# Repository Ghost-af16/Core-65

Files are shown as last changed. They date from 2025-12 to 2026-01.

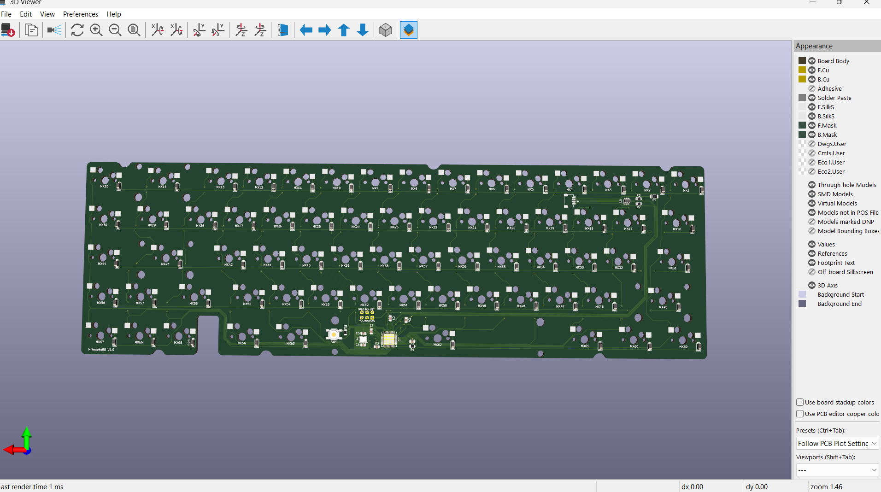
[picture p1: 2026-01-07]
Cart screenshot/Screenshot 2025-12-18 214639.png

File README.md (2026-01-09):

# Core-65
guyss, its a simple 65% layout keyboard with 65 mechanical keys

# FEATURES 
1->> Full Of Functionable Keys 65 </n>

2->> Fully Customizable { Modify The Code For Ur Own Functioning }</n>

# IMAGESSS

















Bill of Materials (BOM)

| Component | Quantity | Specification | Unit Price | Total Price |
|---|---|---|---|---|
| PCB | 5 | Custom PCB | $20 with shipping | $20 with shipping |
| ATMEGA32U4-MU | 1 | Microchip MCU | $6 with shipping | $6 with shipping |
| Crystal | 1 | 16 MHz | $1 with shipping | $1 with shipping |
| Capacitor | 2 | 22 pF | $1 with shipping | $1 with shipping |
| USB-C Receptacle | 1 | USB Type-C | $5 with shipping | $6 with shipping |
| Resistor | 1 | 5.1 kΩ | $0.50 with shipping | $1 with shipping |
| Resistor | 1 | 22 kΩ | $2 with shipping | $2 with shipping |
| Capacitor | 1 | 10 µF | $0.50 with shipping | $1 with shipping |
| Capacitor | 1 | 1 µF | $0.25 with shipping | $1 with shipping |
| Capacitor | 6 | 0.1 µF (100 nF) | $1 with shipping | $2 with shipping |
| Ferrite Bead | 1 | 600 Ω @ 100 MHz | $0.01 with shipping | $0.50 with shipping |
| Key Switch | 68 | Crystal Pro Switch | $33 with shipping | $33 with shipping |
| Key caps | 68 | Blank white cherry | $13 with shipping | $13 with shipping |
| Type c cable | 1 | Type c cable | $7 with shipping | $7 with shipping |
| 3D Printed Case | 1 | Custom 3D Printed Case | Printing Legion | Printing Legion |

## JLCPCB


**INDIA IS GODDAMMED EXPENSIVE MAN**

**Total Estimated Cost**: `$95 WITH SHIPPING CHARGES INCLUDED`

I'm some of the components thats why i'm only asking for the components i dont have

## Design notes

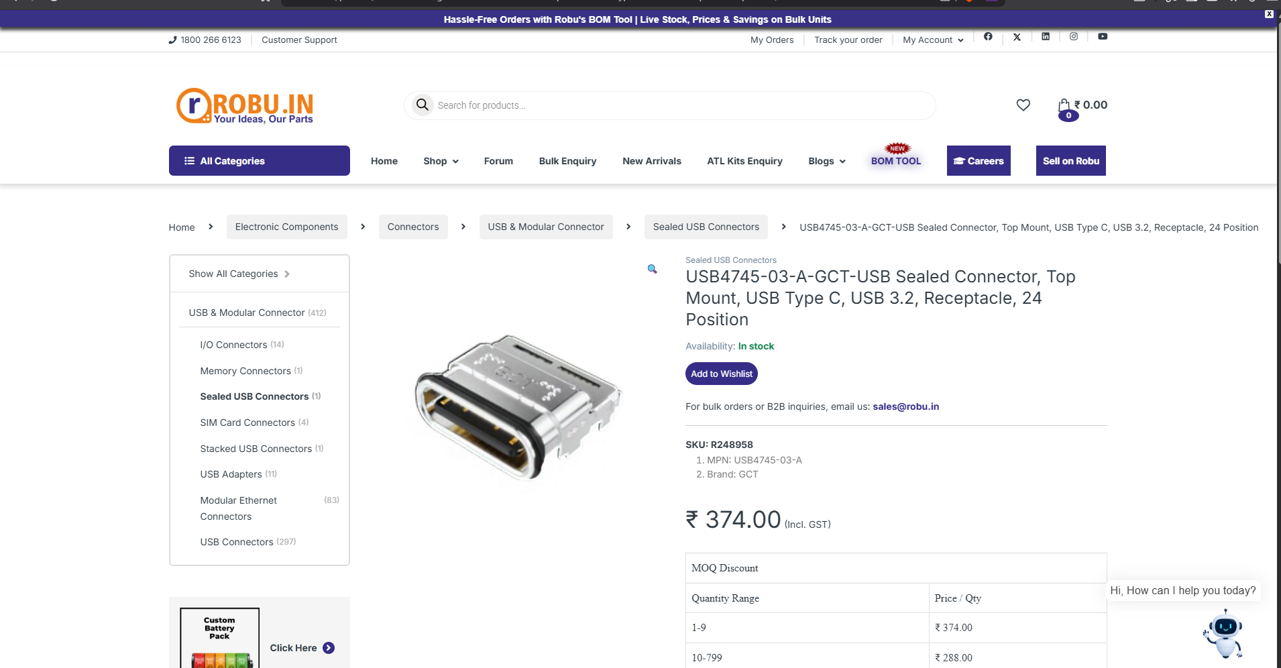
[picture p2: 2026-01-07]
Cart screenshot/Screenshot 2025-12-19 234429.png

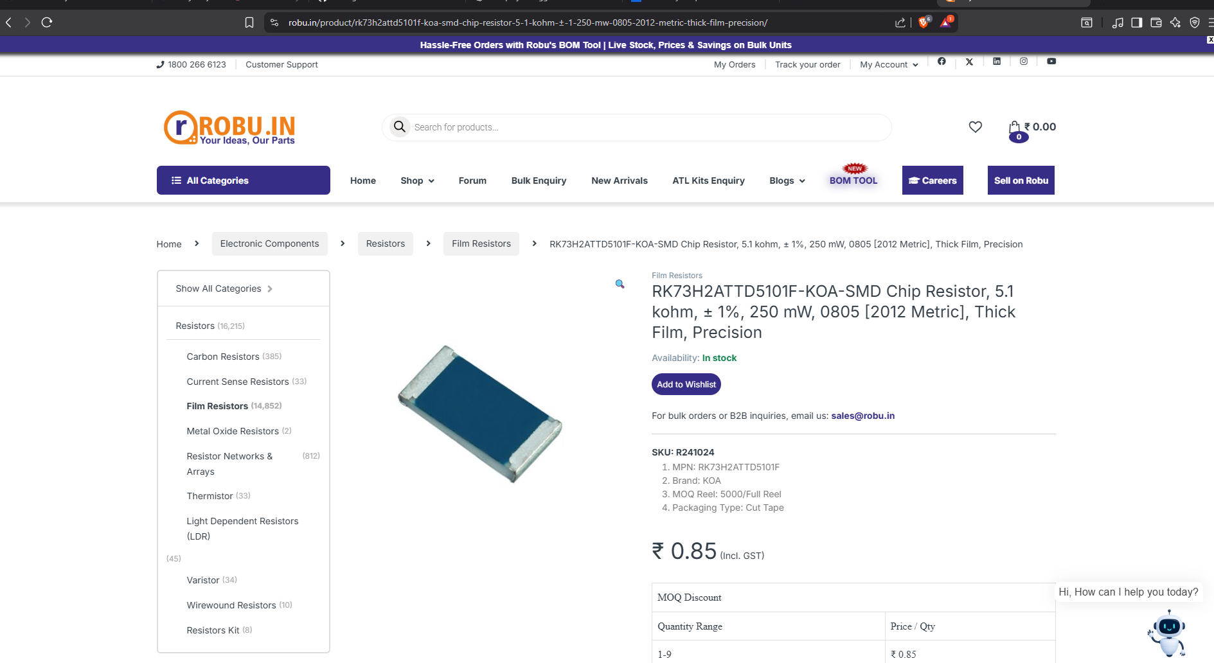
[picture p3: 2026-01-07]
Cart screenshot/Screenshot 2025-12-19 234724.png

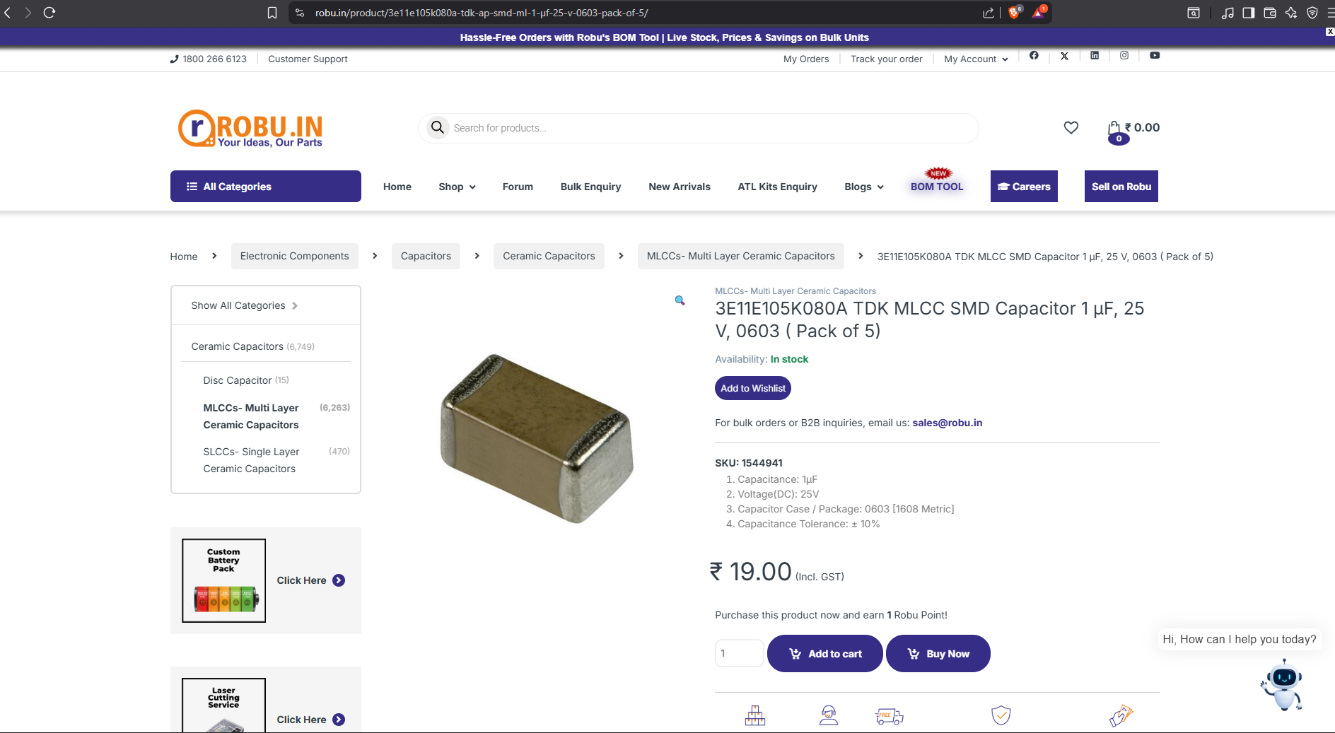
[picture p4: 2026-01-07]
Cart screenshot/Screenshot 2025-12-19 235857.png

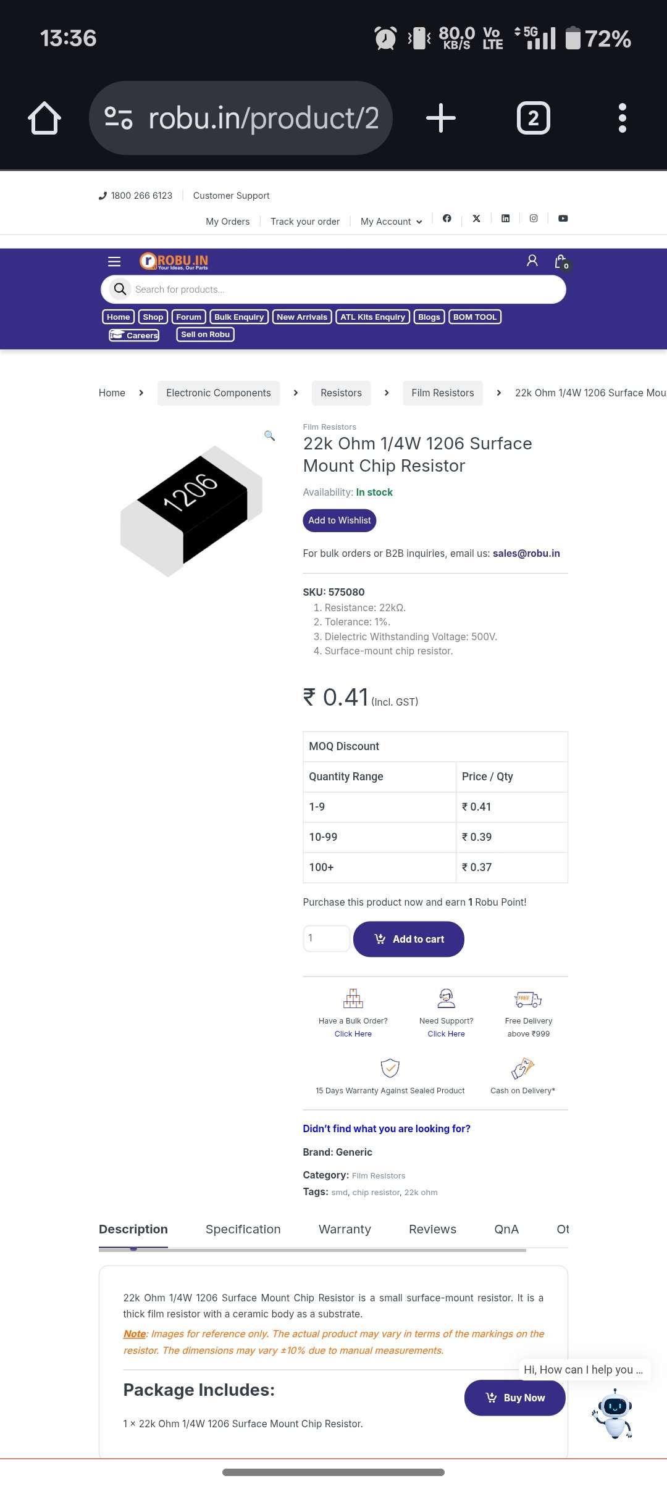
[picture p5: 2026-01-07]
Cart screenshot/Screenshot_2026-01-07-13-36-53-74_40deb401b9ffe8e1df2f1cc5ba480b12.jpg

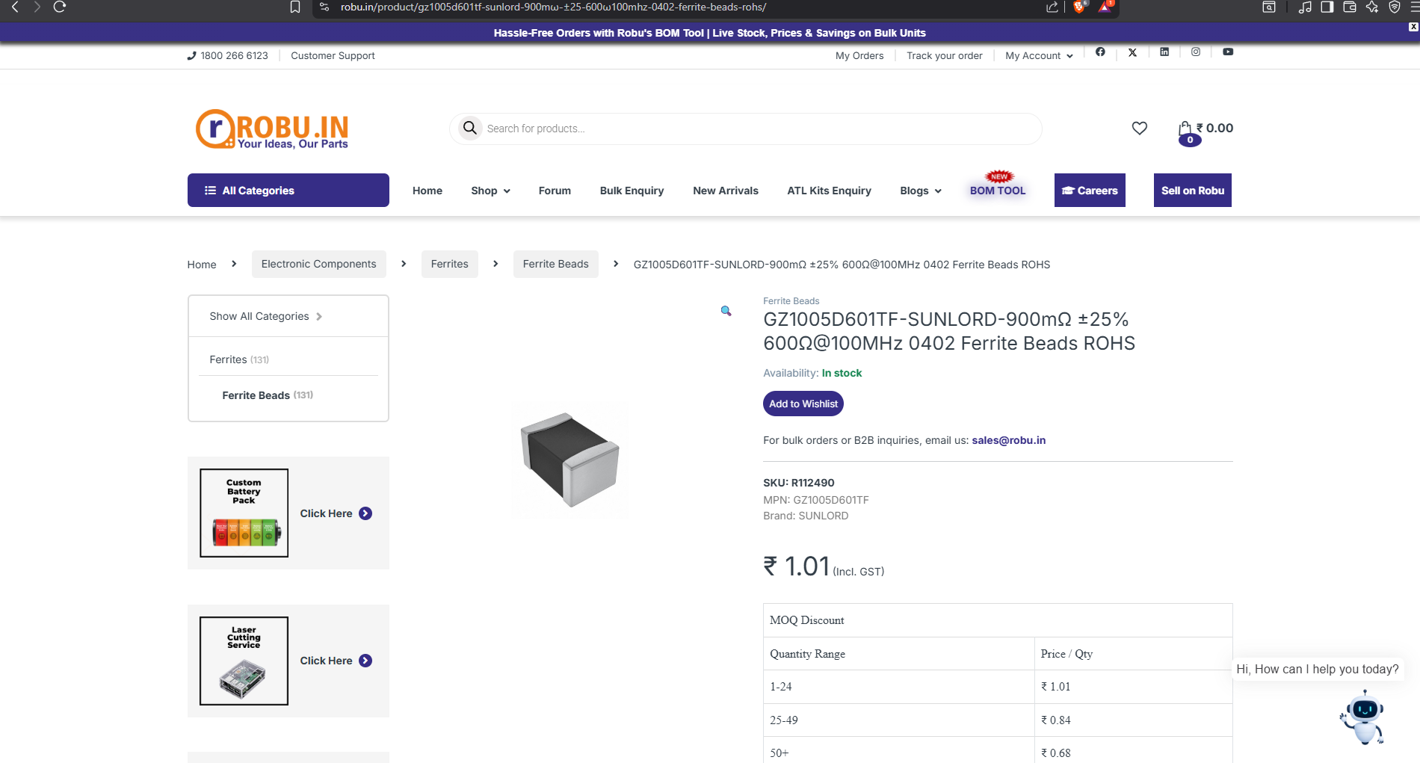
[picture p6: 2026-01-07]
Cart screenshot/Screenshot 2025-12-20 000124.png

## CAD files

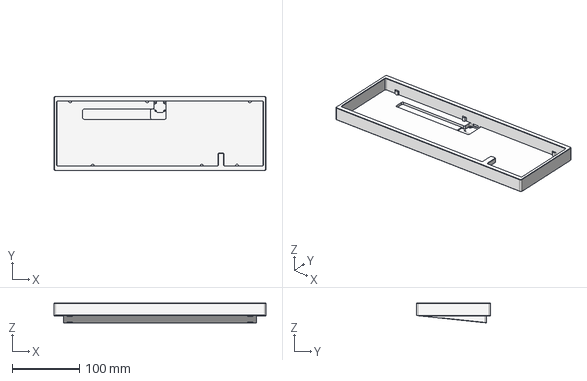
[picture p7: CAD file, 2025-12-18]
CAD/Core-65-bottom case.step
314.8 x 110.2 x 29.4 mm

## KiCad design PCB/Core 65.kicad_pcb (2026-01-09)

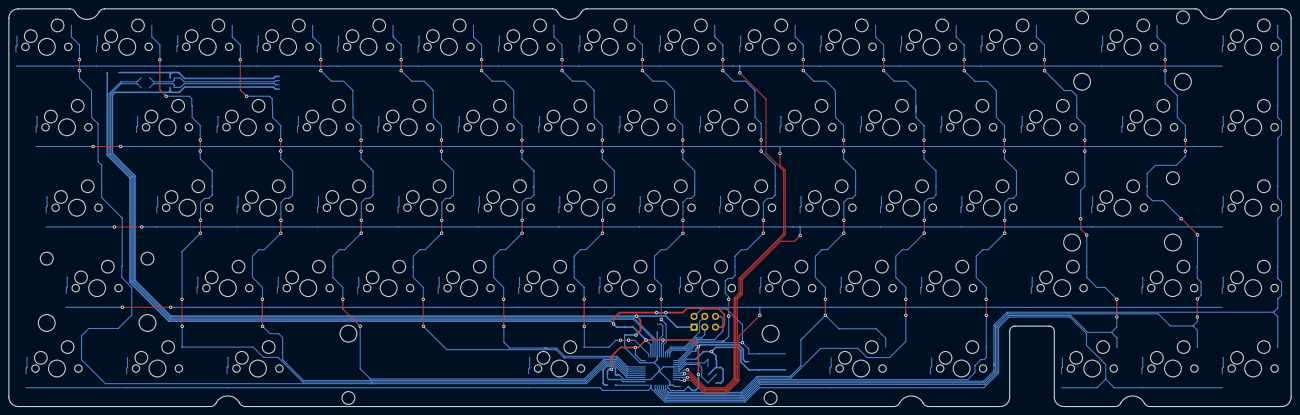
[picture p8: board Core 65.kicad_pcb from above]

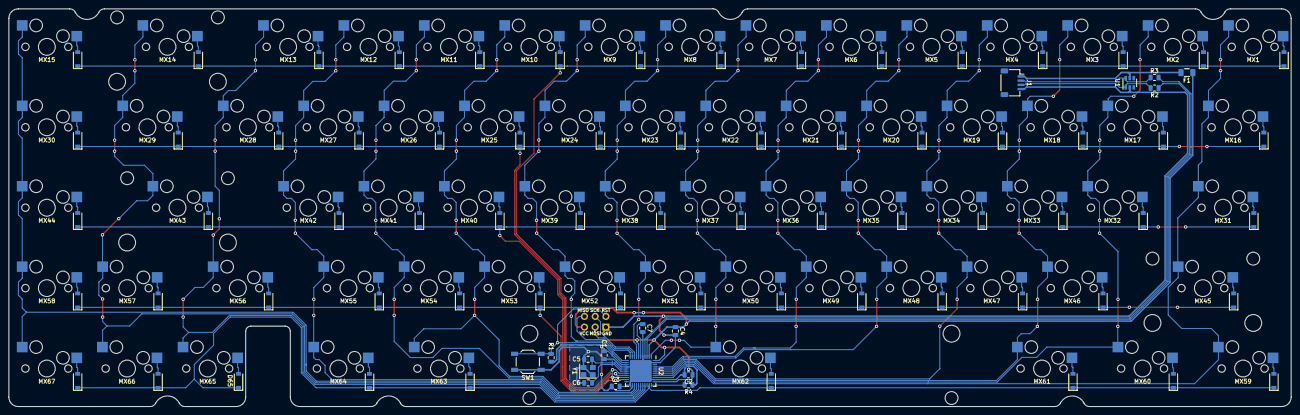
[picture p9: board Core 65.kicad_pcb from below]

Board: 2 copper layers, 303.8 x 94.2 mm, 152 parts (84 on the bottom side), 102 nets.

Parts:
C1, C2, C3: 0.1u; C_0805_2012Metric
C4: 10u; C_0805_2012Metric
C5, C6: 22p; C_0805_2012Metric
C7: 1u; C_0805_2012Metric
D1, D2, D3, D4, D5, D6, D7, D8, D9, D10, D11, D12, D13, D14, D15, D16, D17, D18, D19, D20, D21, D22, D23, D24, D25, D26, D27, D28, D29, D30, D31, D32, D33, D34, D35, D36, D37, D38, D39, D40, D41, D42, D43, D44, D45, D46, D47, D48, D49, D50, D51, D52, D53, D54, D55, D56, D57, D58, D59, D60, D61, D62, D63, D64, D65, D66, D67: 1N4148; D_SOD-123
F1: 500mA; Fuse_1206_3216Metric
J1: JST SH 4-pin; JST_SH_SM04B-SRSS-TB_1x04-1MP_P1.00mm_Horizontal
J2: AVR-ISP-6; ISP
MX1, MX2, MX3, MX4, MX5, MX6, MX7, MX8, MX9, MX10, MX11, MX12, MX13, MX15, MX17, MX18, MX19, MX20, MX21, MX22, MX23, MX24, MX25, MX26, MX27, MX28, MX30, MX32, MX33, MX34, MX35, MX36, MX37, MX38, MX39, MX40, MX41, MX42, MX44, MX46, MX47, MX48, MX49, MX50, MX51, MX52, MX53, MX54, MX55, MX57, MX58, MX65, MX66, MX67: 1u; MXOnly-1U-Hotswap
MX14: 2u; MXOnly-2U-Hotswap
MX16, MX29: 1.5u; MXOnly-1.5U-Hotswap
MX31, MX56: 1.75u; MXOnly-1.75U-Hotswap
MX43, MX45: 2.25u; MXOnly-2.25U-Hotswap
MX59, MX60, MX61, MX63, MX64: 1.25u; MXOnly-1.25U-Hotswap
MX62: 6.25u; MXOnly-6.25U-Hotswap-ReversedStabilizers
R1, R4: 10k; R_0805_2012Metric
R2, R3: 22; R_0805_2012Metric
SW1: Reset; SW_SPST_TL3342
U1: SRV05-4; SOT-23-6
U2: ATmega32U4-MUR; QFN-44-1EP_7x7mm_P0.5mm_EP5.2x5.2mm
Y1: 16MHz; Crystal_SMD_3225-4Pin_3.2x2.5mm

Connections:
+5V: C1.1, C2.1, C3.1, C4.1, F1.1, J2.2, R1.2, U2.2, U2.7, U2.14, U2.24, U2.34, U2.44
/MCU_D+: R2.1, U2.4
/MCU_D-: R3.1, U2.3
COL0: MX1.2, MX16.2, MX31.2, MX45.2, MX59.2, U2.36
COL1: MX2.2, MX17.2, MX32.2, MX60.2, U2.37
COL2: MX3.2, MX18.2, MX33.2, MX46.2, MX61.2, U2.38
COL3: MX4.2, MX19.2, MX34.2, MX47.2, U2.39
COL4: MX5.2, MX20.2, MX35.2, MX48.2, U2.40
COL5: MX6.2, MX21.2, MX36.2, MX49.2, U2.41
COL6: MX7.2, MX22.2, MX37.2, MX50.2, MX62.2, U2.1
COL7: MX8.2, MX23.2, MX38.2, MX51.2, U2.8
COL8: MX9.2, MX24.2, MX39.2, MX52.2, U2.12
COL9: MX10.2, MX25.2, MX40.2, MX53.2, MX63.2, U2.25
COL10: MX11.2, MX26.2, MX41.2, MX54.2, U2.26
COL11: MX12.2, MX27.2, MX42.2, MX55.2, MX64.2, U2.27
COL12: MX13.2, MX28.2, MX56.2, MX65.2, U2.30
COL13: MX14.2, MX29.2, MX43.2, MX57.2, MX66.2, U2.29
COL14: MX15.2, MX30.2, MX44.2, MX58.2, MX67.2, U2.28
D+: J1.3, R2.2, U1.1
D-: J1.2, R3.2, U1.6
GND: C1.2, C2.2, C3.2, C4.2, C5.1, C6.1, C7.2, J1.4, J2.6, R4.1, SW1.1, U1.2, U2.5, U2.15, U2.23, U2.35, U2.43, U2.45, Y1.2, Y1.4
MISO: J2.1, U2.11
MOSI: J2.4, U2.10
unnamed: C7.1, U2.6
unnamed: D1.2, MX1.1
unnamed: D2.2, MX2.1
unnamed: D3.2, MX3.1
unnamed: D4.2, MX4.1
unnamed: D5.2, MX5.1
unnamed: D6.2, MX6.1
unnamed: D7.2, MX7.1
unnamed: D8.2, MX8.1
unnamed: D9.2, MX9.1
unnamed: D10.2, MX10.1
unnamed: D11.2, MX11.1
unnamed: D12.2, MX12.1
unnamed: D13.2, MX13.1
unnamed: D14.2, MX14.1
unnamed: D15.2, MX15.1
unnamed: D16.2, MX16.1
unnamed: D17.2, MX17.1
unnamed: D18.2, MX18.1
unnamed: D19.2, MX19.1
unnamed: D20.2, MX20.1
unnamed: D21.2, MX21.1
unnamed: D22.2, MX22.1
unnamed: D23.2, MX23.1
unnamed: D24.2, MX24.1
unnamed: D25.2, MX25.1
unnamed: D26.2, MX26.1
unnamed: D27.2, MX27.1
unnamed: D28.2, MX28.1
unnamed: D29.2, MX29.1
unnamed: D30.2, MX30.1
unnamed: D31.2, MX31.1
unnamed: D32.2, MX32.1
unnamed: D33.2, MX33.1
unnamed: D34.2, MX34.1
unnamed: D35.2, MX35.1
unnamed: D36.2, MX36.1
unnamed: D37.2, MX37.1
unnamed: D38.2, MX38.1
unnamed: D39.2, MX39.1
unnamed: D40.2, MX40.1
unnamed: D41.2, MX41.1
unnamed: D42.2, MX42.1
unnamed: D43.2, MX43.1
unnamed: D44.2, MX44.1
unnamed: D45.2, MX45.1
unnamed: D46.2, MX46.1
unnamed: D47.2, MX47.1
unnamed: D48.2, MX48.1
unnamed: D49.2, MX49.1
unnamed: D50.2, MX50.1
unnamed: D51.2, MX51.1
unnamed: D52.2, MX52.1
unnamed: D53.2, MX53.1
unnamed: D54.2, MX54.1
unnamed: D55.2, MX55.1
unnamed: D56.2, MX56.1
unnamed: D57.2, MX57.1
unnamed: D58.2, MX58.1
unnamed: D59.2, MX59.1
unnamed: D60.2, MX60.1
unnamed: D61.2, MX61.1
unnamed: D62.2, MX62.1
unnamed: D63.2, MX63.1
unnamed: D64.2, MX64.1
unnamed: D65.2, MX65.1
unnamed: D66.2, MX66.1
unnamed: D67.2, MX67.1
unnamed: R4.2, U2.33
RESET: J2.5, R1.1, SW1.2, U2.13
ROW0: D1.1, D2.1, D3.1, D4.1, D5.1, D6.1, D7.1, D8.1, D9.1, D10.1, D11.1, D12.1, D13.1, D14.1, D15.1, U2.18
ROW1: D16.1, D17.1, D18.1, D19.1, D20.1, D21.1, D22.1, D23.1, D24.1, D25.1, D26.1, D27.1, D28.1, D29.1, D30.1, U2.19
ROW2: D31.1, D32.1, D33.1, D34.1, D35.1, D36.1, D37.1, D38.1, D39.1, D40.1, D41.1, D42.1, D43.1, D44.1, U2.20
ROW3: D45.1, D46.1, D47.1, D48.1, D49.1, D50.1, D51.1, D52.1, D53.1, D54.1, D55.1, D56.1, D57.1, D58.1, U2.21
ROW4: D59.1, D60.1, D61.1, D62.1, D63.1, D64.1, D65.1, D66.1, D67.1, U2.32
SCK: J2.3, U2.9
VBUS: F1.2, J1.1, U1.5
XTAL1: C6.2, U2.17, Y1.1
XTAL2: C5.2, U2.16, Y1.3

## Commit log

2025-12-18 Create README.md for DevBoard X project
    Added README.md with project details, features, images, and BOM.
2025-12-19 Create BOM.csv with components and pricing
    Added a Bill of Materials (BOM) with components, quantities, specifications, and prices.
    [BOM.csv]
2025-12-20 Revise BOM.csv for clarity and accuracy
    Updated the Bill of Materials with improved formatting and corrected component specifications.
    [BOM.csv]
2026-01-07 Adjust component prices in BOM.csv
    Updated prices for components in the BOM.
    [BOM.csv]
2026-01-07 Fix pricing for 10 µF capacitor in BOM
    Updated unit price and total price for one capacitor.
    [BOM.csv]

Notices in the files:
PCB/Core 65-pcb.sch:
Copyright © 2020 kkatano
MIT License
